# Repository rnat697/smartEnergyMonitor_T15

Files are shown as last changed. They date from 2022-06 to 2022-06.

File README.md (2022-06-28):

# Smart Energy Monitor Team 15
Smart Energy Monitor Project for University (Analogue And Digital Design, 2021)
###### Authors: Rachel Nataatmadja, Shou Miyamoto, Francis Cho, Martin Wu 
University group project that develops an energy monitor to measure and display the amount of energy consumed by a household appliance.

- Developed the embedded software program in C for the energy monitor that converts analogue signals to digital form and calculates the energy consumption.
- Designed the PCB using Altium PCB Designer.
- Developed and simulated analogue circuitry to fit specifications.

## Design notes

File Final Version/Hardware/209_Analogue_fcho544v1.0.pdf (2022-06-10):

Francis Cho | COMPSYS/ELECTENG 209 v1.0 | 2021

# COMPSYS/ELECTENG 209 – Progress Review Preparation

Analogue Design

You are expected to deliver an LTspice simulation model of your team’s final analogue design, which should have the functionalities listed below,

1. Voltage and current sensing circuit design (Lab 1 Q3 & Q4)
2. Level-shifting and amplification circuit design for both voltage and current sensors (Lab 2 Q2 & Q3)
3. Filter circuit designs for both voltage and current sensors (Lab 2 Q4)
4. 5V regulator circuit design (Lab 2 Q5)
5. Circuitry to generate the offset voltage supplied to the Op-Amp (Lab 2 Q5)
6. Voltage zero crossing detector circuit design

The model should be in a single LTspice file, neatly drawn with text comments to help us understand your design (you may copy-paste LTspice model given for Lab 2 and use it as a template - remove unwanted parts, rearrange to make it tidy and add extra parts as needed). Read LTspice Simulations (https://canvas.auckland.ac.nz/courses/60945/assignments/218159) to understand how we will assess and test your model.

Part 1: Voltage and current sensing circuit design (Lab 1 Q3 & Q4)

Instructions from Lab 1 Part 3

Part 3: Sensing AC Load Current Your analogue circuitry should sense the current through the AC load as well as the voltage supplied by the AC source.

Current sensor: can be measured using a shunt resistor, which produces a voltage drop that is proportional to the current flowing through it. Because the microcontroller ADC can only read analogue voltages and convert them to digital numbers. Therefore, we must convert the current to a corresponding voltage before it can be fed to an ADC channel through a signal conditioning circuit.

CURRENT SENSOR

Selected Shunt Resistor (RS): 0.565 Ohms

Working for Q2.1 (Calculating maximum and minimum current)

S = I

2Z

S =

V

2
Z

7.5 =

12.6

2
Z

Z = 21.168

I

2 =

S
Z

=

7.5
21.168

Imax = 0.595 A

S = I

2Z

S =

V

2
Z

2.5 =

15.4

2
Z

Z = 94.864

I

2 =

S
Z

=

2.5
94.864

Imin = 0.16234 A

Francis Cho | COMPSYS/ELECTENG 209 | 2021

Shunt resistor Calculations at P = 200 mW:

P = I

2Rs
At Iminimum = 0.162 A, | Rs = 5.589 Ω
At Imaximum = 0.595 A, | Rs = 0.5649 Ω

Lab 1 Q 3.2 Sensing the load current

Calculation of first row: @ 7.5 VA and 12.6 V

Finding R(load)

S =

V

2
Z

=

V

2
√R² + Z
2

√R² + Z
2 =

V

2
S

R

2 = (
V

2
S

)

2
− Z

2 = (
12.6

2
7.5

)

2
− (4π)

2

R = 17.034 Ω

And at 7.5 VA and 12.6 V we know this gives the maximum current, therefore I = 0.595 A

I = √
S
Z

= √
7.5
√17² + (4π)
2

= √
7.5
21.168 = 0.595 A

Vis

(pk) is the peak of the observed amplitude of sensed voltage:

Vis(pk) =

Rs
Rs + Z

(V)(√2)

Vis(pk) =

0.565
0.565 + 21.14

(12.6)(√2)

Vis(pk) = 0.4638 V

Pis is the power dissipated across the shunt resistor:

Pis =

V

2
R

=

(

0.4638
√2

)

2

0.565 = 0.19036 W = 190.36 mW

Additional comments: Since the power dissipated at the highest current is below 200 mW, we will use the smaller shunt resistor value in our current sensor.

VOLTAGE SENSOR Lab 1 Q4: Sensing AC Source Voltage

- Since the ADC of your microcontroller can only measure voltages in the range from 0V to 5V
- Voltage sensor should step-down to be within this range.
- Achieved by using a voltage divider circuit.
- The voltage divider will translate the high voltage AC input to a lower and safer voltage before feeding it into an ADC channel through its own signal conditioning circuit.
- Maximum load voltage to about 2Vpk-pk

2 Vpk−pk is equivalent to 1 Vpk

Vout =

Rb
Rb + Ra

(Vin)

1 Vpk =

Rb
Rb + 56 k

(15.6)(√2)

Rb = 2.7 kΩ (E12 value)

Note: Ra = 56 kΩ was a random high E12 resistor value, other combinations can work with different Ra values

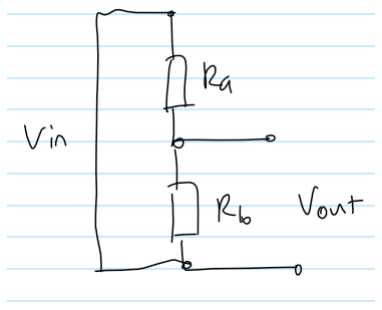
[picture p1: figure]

Q 4.2 Verify voltage divider and check power dissipated

Calculation of first row: @ 7.5 VA & 12.6 V

RL = 17 Ω, IL(RMS) = 0.595 A

Vvs(pk) =

2.7k
2.7k + 56k

(12.6)(√2) = 0.8196 V

Pvs =

Vrms

2
R

=

(

0.8196
√2

)

2

3920 = 0.1244 mW

Add notes on SNR, Dissipations (Pis), Sensitivity

Part 2: Level-shifting and amplification circuit design for both voltage and current sensors (Lab 2 Q2 & Q3)

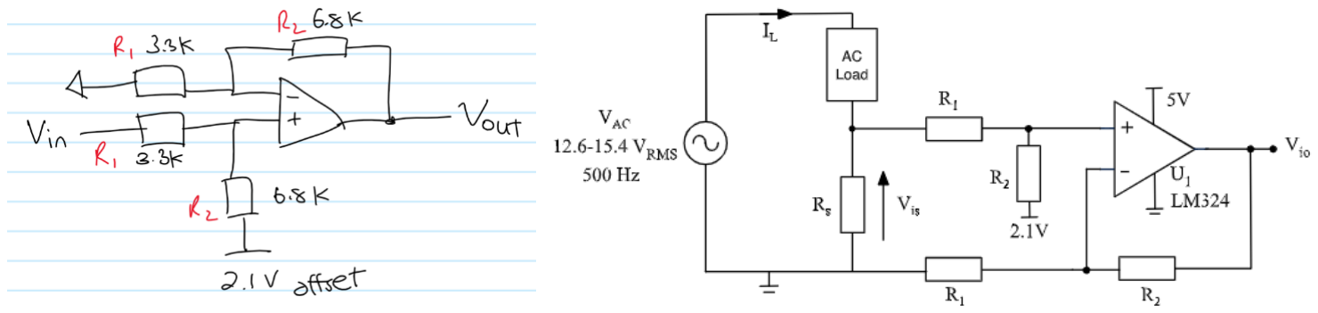
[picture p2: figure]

To determine the resistor values R1 and R2 that is required to produce output that has 2 Vpk-pk and 2.1V offset, we can find the ratio between amplitude (1 V) and maximum input Vis

Vout = (

R2
R1

) Vin

1 Vpk = (

R2
R1

) (0.4638)

R2
R1

= 2.156

Let R2 = 7 kΩ, then R1 = 3.246 kΩ

Converting to E12 resistor values, we will get R2 = 6.8 kΩ and R1 = 3.3 kΩ

Lab 2 Q 2.2 Table

Calculation of first row: @ 7.5 VA and 12.6 V

Vis(pk) =

Rs
Rs + ZL

(Vac(pk)) =

0.565
0.565 + √17² + (4π)
2

(12.6)(√2) = 0.46384 V

Vio(pk) = Vref + Vis(pk) (

R2
R1

)

Vio(pk) = 2.1 + (0.4638) (

6.8 k
3.3 k

) = 3.055709 V

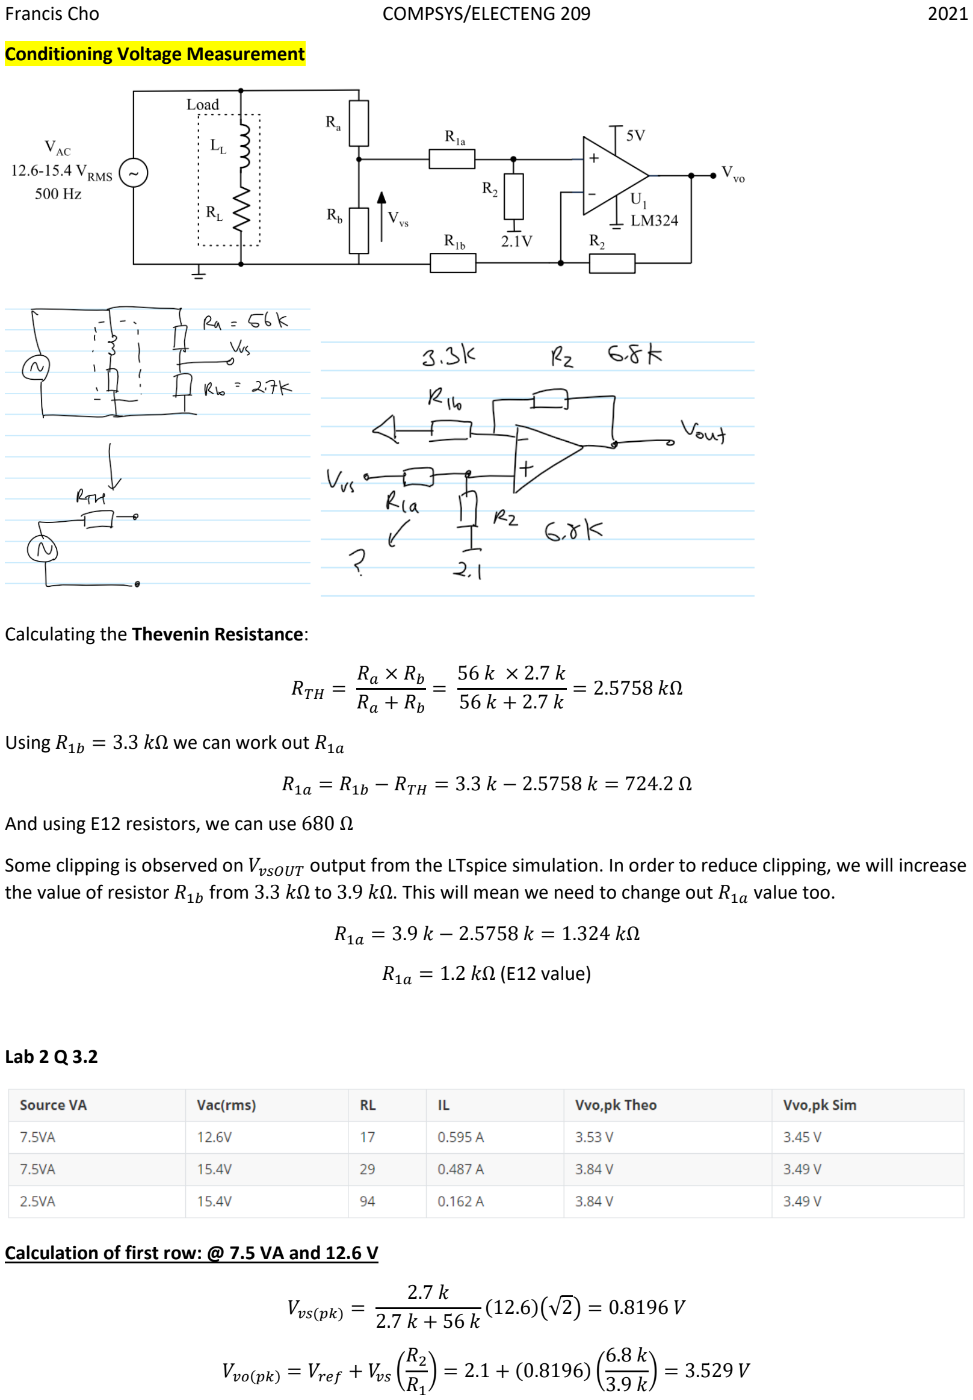
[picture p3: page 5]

Conditioning Voltage Measurement

Calculating the Thevenin Resistance:

RTH =

Ra × Rb
Ra + Rb

=

56 k × 2.7 k
56 k + 2.7 k

= 2.5758 kΩ

Using R1b = 3.3 kΩ we can work out R1a

R1a = R1b − RTH = 3.3 k − 2.5758 k = 724.2 Ω

And using E12 resistors, we can use 680 Ω

Some clipping is observed on VvsOUT output from the LTspice simulation. In order to reduce clipping, we will increase the value of resistor R1b from 3.3 kΩ to 3.9 kΩ. This will mean we need to change out R1a value too.

R1a = 3.9 k − 2.5758 k = 1.324 kΩ

R1a = 1.2 kΩ (E12 value)

Lab 2 Q 3.2

Calculation of first row: @ 7.5 VA and 12.6 V

Vvs(pk) =

2.7 k
2.7 k + 56 k

(12.6)(√2) = 0.8196 V

Vvo(pk) = Vref + Vvs (

R2
R1

) = 2.1 + (0.8196) (

6.8 k
3.9 k

) = 3.529 V

Part 3: Filter circuit designs for both voltage and current sensors (Lab 2 Q4)

- Signals from op amp contain lots of high-frequency electrical noise
- Due to aliasing the noise will introduce error in digital values obtained by C program

Transfer function of

Vfilter

VOpAmp

Vfilter

VOpAmp

=

Xc
Z

=

Xc
√R² + Xc
2

Cut-off frequency at 10 kHz

fc =

1
2πRC

Let R = 1 kΩ

10 kHz =

1
2π(1 kΩ)C

C = 15.915 nF

Bode Magnitude and phase plots:

Magnitude → the modulus of the transfer function.

Phase → this only matters if there are more components e.g. voltage and current, they could be out of phase which could introduce inaccuracies in calculations

Part 4: 5V regulator circuit design (Lab 2 Q5)

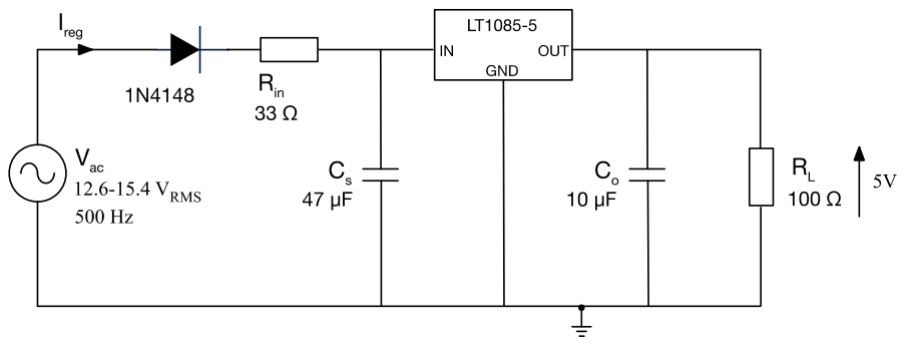
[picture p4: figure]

Cin =

IinTg

ΔVin

ΔVin =

(50 mA) (

1
500 Hz

)

47 nF

ΔVin = 2.12765 V

Part 5: Circuitry to generate the offset voltage supplied to the Op-Amp (Lab 2 Q5)

Buffer is used in addition to a voltage divider to derive 2.1 V offset.

- Advantages of buffers: zero resistance and constant voltage
- Disadvantages: limited output current

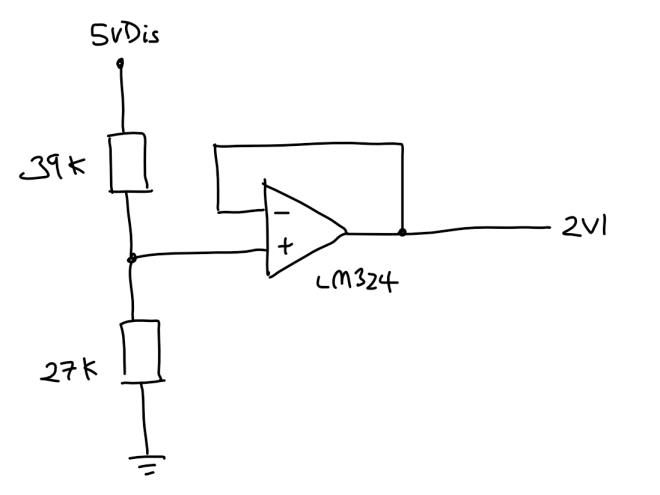
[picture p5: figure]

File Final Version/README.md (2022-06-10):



# Welcome to Your EE209 Project Repository

- Code, simulations and other files relating to your final project implementation should be in this folder
 - You can create folders to organize your work (e.g. PCB, Firmware, Software, LTspice, Proteus, etc.)
- Unless you are quite familiar with Git, do your individual work in your own folder and manually migrate the final solutions to this folder (i.e. copy-paste relevant parts from your folder to this folder)

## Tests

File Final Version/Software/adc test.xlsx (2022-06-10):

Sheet: Sheet15
Column1 | Column2 | Column1 | Column2 | Column1 | Column2 | Column1 | Column2
3085 | 2768 | 3164 | 2060 | 429 | 1723 | 2680 | 2734 | bug fix since 16/10/21
2050 | 2539 | 3769 | 2475 | 458 | 1455 | 2348 | 2592 | 10:49pm
1035 | 2138 | 3740 | 2744 | 1118 | 1430 | 1923 | 1513 | at least it works for the first 3 ones
429 | 1723 | 3085 | 2768 | 2148 | 1665 | 1567 | 664
458 | 1455 | 2050 | 2539 | 3164 | 2060 | 458 | 356
1118 | 1430 | 1035 | 2138 | 3769 | 2475 | 1118 | 1430
2148 | 1665 | 429 | 1723 | 3740 | 2744 | 2148 | 1665
3164 | 2060 | 458 | 1455 | 3085 | 2768 | 3164 | 2060
3769 | 2475 | 1118 | 1430 | 2050 | 2539 | 3769 | 2475
3740 | 2744 | 2148 | 1665 | 1035 | 2138 | 3740 | 2744
3085 | 2768 | 3164 | 2060 | 429 | 1723 | 3085 | 2768
2050 | 2539 | 3769 | 2475 | 458 | 1455 | 2050 | 2539
1035 | 2138 | 3740 | 2744 | 1118 | 1430 | 1035 | 2138
429 | 1723 | 3085 | 2768 | 2148 | 1665 | 429 | 1723
458 | 1455 | 2050 | 2539 | 3164 | 2060 | 458 | 1455
1118 | 1430 | 1035 | 2138 | 3769 | 2475 | 1118 | 1430
2148 | 1665 | 429 | 1723 | 3740 | 2744 | 2148 | 1665
3164 | 2060 | 458 | 1455 | 3085 | 2768 | 3164 | 2060
3769 | 2475 | 1118 | 1430 | 2050 | 2539 | 3769 | 2475
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

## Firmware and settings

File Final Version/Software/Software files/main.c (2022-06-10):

/*
 * UART Implementation.c
 *
 * Created: 22/08/2021 7:51:22 pm
 * Author : Shou M,Rachel N
 */ 

#define F_CPU 2000000UL
#include <avr/io.h>
#include <stdio.h>
#include <avr/interrupt.h>
#include "uart.h"
#include "functions.h"
#include "adc.h"
#include "timer.h"
#include "displayDriver.h"
#include "signalAnalysis.h"
#include <util/delay.h>


char stringVoltage[] = {"Peak Voltage is: "};
char stringCurrent[]= {"RMS Current is: "};
char stringPower[]={"Power is: "};
float Vac, power;
uint16_t Irms;

//////////// MACROS ///////////
#define voltageDp 1
#define currentDp 4 
#define powerDp 0
#define DISABLEINTTIMER0	TIMSK0 &= ~(1 << OCIE0A);
#define ENABLEINTTIMER0		TIMSK0 |= (1<<OCIE0A);
#define SCROLLRATE 1000
#define BAUDRATE 9600
///////////////////////////////

int main(void){
	
	//Initialisations
	 DDRB |= (1<<PB5) ;    // Set led as output, validation for the ISR and timers.
	 DDRC = 0x00;		//sets all to input register
	 DDRD = 0x00;       // keeps register as input
	 
	 timer0_init(); // timer for ADC sampling
	 timer1_init(); // Timer for 7 Segement refresh rate
	 adc_init();	//initialize adc register
	 usart_init(BAUDRATE);
	 sei();	//turns interrupt on
	 
	
	//DISPLAY 
	initDisplay(); //initalise display
	
	 
	seperate_and_load_characters(0,4); // initial
	while(1){
		// Once all the sampling has been finished
		if(sampleNum == 80){
			
			DISABLEINTTIMER0;  // disable outputcompare
			// Convert ADC0 and ADC1 values to voltage signal values (in mV)
			convertADCtoVoltage();
			
			// calculates Peak Voltage (V), RMS current (mA) and Power (W)
			Vac = calculatePeakVoltage();
			Irms = calculateRMSCurrent();
			power = calculatePower();
			
			// transmit Voltage to terminal   //XY.Z
			transmitChars(stringVoltage);
			separateVoltage(Vac);
			
			// Transmit current RMS to terminal 	//XYZ
			transmitChars(stringCurrent);
			separateCurrent(Irms);
			
			
			// Transmit Power to terminal //X.YZ
			transmitChars(stringPower);
			separatePower(power);
			usart_transmit(0x0a); // new line \n
			usart_transmit(0x0d); // new line \r
			
			// Transmit peak Voltage, Current RMS and power to 7 segment display
			seperate_and_load_characters(Vac, voltageDp);
			_delay_ms(SCROLLRATE);
			seperate_and_load_characters(Irms, currentDp);
			_delay_ms(SCROLLRATE);
			seperate_and_load_characters(power, powerDp);
			_delay_ms(SCROLLRATE);
			
			// Start sampling again
			ENABLEINTTIMER0;	//Enable interrupt for timer0 output compare match
			// Enable ADC sampling again
			enableADC();
		}
		

	}
}

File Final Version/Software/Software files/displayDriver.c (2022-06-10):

/*
 * displayDriver.c
 *
 * Created: 26/08/2021 5:55:20 PM
 *  Author: Rachel N,  Shou M
 */ 
#include "displayDriver.h"
#include "timer.h"

#define SH_DS1 PORTC |= (1<<PC4)         // Sets SH_DS pin to 1
#define SH_DS0 PORTC &= ~(1<<PC4)        // Sets SH_DS pin to 0
#define SH_CPTOGGLE PORTC ^= (1<<PC3)    //SH_DS pin C4    data being transferred.
#define SH_STTOGGLE PORTC ^= (1<<PC5)    //SH_ST pin C5    loads all of it, on and off at the very end
#define SH_CPOFF PORTC &= ~(1<<PC3);	 // set SH_CP to logic 0
#define SH_STOFF PORTC &= ~(1<<PC5);	 // set SH_ST to logic 0

//all LED segment values for PortC
#define LED0   0b00111111
#define LED1   0b00000110
#define LED2   0b01011011
#define LED3   0b01001111
#define LED4   0b01100110
#define LED5   0b01101101
#define LED6   0b01111101
#define LED7   0b00000111
#define LED8   0b01111111
#define LED9   0b01101111
#define LEDP   0b01110011
#define LEDV   0b00111110
#define LEDA   0b01110111

// Enable and disable I/O pins for digit DS1,DS2,DS3 and DS4
#define DS1ON PORTD &= ~(1<<PD4)
#define DS2ON PORTD &= ~(1<<PD5)
#define DS3ON PORTD &= ~(1<<PD6)
#define DS4ON PORTD &= ~(1<<PD7)
#define DISPOFF PORTD|= (1<<PD4),PORTD|= (1<<PD5),PORTD|= (1<<PD6),PORTD|= (1<<PD7)
#define voltageDp 1
#define currentTempDp 4
#define powerDp 0
#define STARTUP 0


static volatile uint8_t disp_position = 0;
static volatile uint8_t binaryArray[8];
static volatile	uint8_t disp_characters[4];

void initDisplay(){
	DDRC |= (1<<PC3); // set SH_CP as output
	DDRC |= (1<<PC4); // set SH_DS as output
	DDRC |= (1<<PC5); // set SH_ST as output
	
	DDRD |= (1<<PD4); // Set DS1 as output
	DDRD |= (1<<PD5); // Set DS2 as output
	DDRD |= (1<<PD6); // Set DS3 as output
	DDRD |= (1<<PD7); // Set DS4 as output
	
}

void send_next_character_to_display(){
	// Get the binary segment values of the character that we want to display based on the display position
	convertDecimaltoBinary(disp_characters[disp_position]);
	SH_CPOFF; // set SH_CP to logic 0
	SH_STOFF; // set SH_ST to logic 0
	
	// Sending segment bit pattern to shift registers
	for(uint8_t i=0; i<8; i++){
	
		//Set the SH_DS pin to be either “0” or “1” as per the bit
		if(binaryArray[i] == 1){
			SH_DS1;
			}else{
			SH_DS0;
		}
		
		// SH_CP toggles to shift in bit to shift register
		SH_CPTOGGLE;
		SH_CPTOGGLE;
	}
	
	// Disable Digits
	DISPOFF;
	
	// Latch the output (l set the 8-bit pattern from the shift register to drive the segments)
	SH_STTOGGLE;
	SH_STTOGGLE;
	
	// Enable the corresponding digit position (i.e. set Ds1, Ds2, Ds3 and Ds4)
	if (disp_position ==0){
		DS1ON;
		
		}else if(disp_position == 1){
		DS2ON;
		
		}else if(disp_position == 2){
		DS3ON;
		
		}else if(disp_position == 3){
		DS4ON;
		
	}
	disp_position++; // increment display position for next function call
	
	// Reset disp_position after 3
	if(disp_position >3){
		disp_position = 0;
	}
}

void convertDecimaltoBinary(uint8_t num){
	uint8_t newNum = num;
	uint8_t position = 1;
	
	// Reset binary array
	for(uint8_t j =0; j<8;j++){
		binaryArray[j] = 0;
	}
	
	// calculate binary values and store them in an array (MSB on the left most element and LSB on right most)
	while (newNum > 0) {
		binaryArray[8-position] = newNum % 2;   // calculates the bit and loads it into the array in reverse order
		newNum = newNum / 2; // next number for iteration
		position++;
	}
}

void seperate_and_load_characters(float number, uint8_t decimal_pos){
	uint8_t seg_pattern[10] ={LED0,LED1,LED2,LED3,LED4,LED5,LED6,LED7,LED8,LED9};
	uint8_t thousands,hundreds,tens,ones,maxPos;
	uint8_t add_decimalPoint = 128;

	// Separate the numbers
	if (number == STARTUP){ // to show 0's on start up
		thousands = number/1000;
		hundreds = (number - thousands*1000)/100;
		tens = (number - thousands*1000 - hundreds*100)/10;
		ones = (number - thousands*1000 - hundreds*100 - tens*10);
		maxPos = 4;// to display 0 on all 4 segements
	
	}// To separate numbers of currentRMs, peak voltage or power
	else if(decimal_pos == voltageDp){ //Peak voltage number separation
		number = number*10; // Change to XYZ from XY.Z for easy separation
		
		thousands = number/100;
		hundreds = (number - thousands*100)/10;
		tens = (number - thousands*100 - hundreds*10);
		
		maxPos = 3; // to be able to display the numbers on 3 segments and the last segment has the unit
		disp_characters[3] = LEDV;  // Store the binary segment pattern for current unit A to use in DS4
		
		// Current RMS number separation
	}else if(decimal_pos == currentTempDp && number!=STARTUP ){ // Current is displaying in mA
		
		thousands = number/100;
		hundreds = (number - thousands*100)/10;
		tens = (number - thousands*100 - hundreds*10);
		maxPos = 3;
		disp_characters[3] = LEDA; // Store the binary segment pattern for current unit A to use in DS4
		
		// Power number separation
	} else if (decimal_pos == 0){
		number = number*100; // Change to XYZ from X.YZ for easy separation
		
		thousands = number/100;
		hundreds = (number - thousands*100)/10;
		tens = (number - thousands*100 - hundreds*10);
		maxPos = 3;
		disp_characters[3] = LEDP;
		
	}
	
	//Add to array
	uint8_t numberArray[4]={thousands,hundreds,tens,ones};
	
	// cycles through numbers array to find corresponding segment pattern
	for (int i=0;i<maxPos;i++){
		if(i==decimal_pos)
		{
			disp_characters[i] = seg_pattern[numberArray[i]]+add_decimalPoint; // Add corresponding segment pattern to display characters array for transmission
			// Add 128 because we want dp is on the 7th bit and we want to turn that on
			
			}else{
			//takes number from array and then finds its pattern.
			disp_characters[i]= seg_pattern[numberArray[i]];
		}
	}
	
}
